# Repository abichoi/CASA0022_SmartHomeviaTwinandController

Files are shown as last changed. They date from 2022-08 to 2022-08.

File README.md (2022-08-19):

# Can the concept of a smart home be used in a small living space and linked to a physical model with two-way communication for real-time IoT data?
This repository is a part of a dissertation for UCL MSc Connected Environments.

## Hypothesis: Deploying a smart home system in a small living space via a physical twin and controller communication model.

## Aims
The aims of this dissertation is to investigate the possibility of deploying a smart home in a small living space and utilise the data collected by the smart home system through a physical ‘twin’ model. 

## Methodology 
A smart home based on Home Assistant is deployed in a student accomadation studio room with the following layout.

In addition, a physical twin and a controller are 3D printed and laser cut.

### Circuits  
#### Physical Twin  
  
  
#### Controller  
  

### Code
[Code Explanation](https://github.com/abichoi/CASA0022_SmartHomeviaTwinandController/blob/main/Physical_Devices_Code/Code_Explanation.md)

## Results
It is possible to deploy a smart home in a small living space and utilise the data collected by the smart home outside the system via a physical twin and controller. However, it is noted that the potential of the smart home is limited as it is easy for sensors' detection areas to overlay and it is difficult to differentiate different activitis in the same area.

## Demostration
A demonstration video of HASS Automations used in this dissertation on YouTube (https://youtu.be/vFsg55t07NU)

## Resulted Devices
### Physical Twin with 3D Printed Walls


### Physical Twin with Laser Cut Walls


### Controller with 3D Printed Cover


### Controller with Laser Cut Cover
  

### Self Built Air Monitor


## Used Softwares and Hardwares
### General
1. Modeling Software: Autodesk Fusion 360
2. 3D Printer: Original Prusa i3 MK3S+ 3D printer

### Physical Twin
1. Laser Cutter: Piranha Bodor laser cutter/ Trotec laser cutter
2. Laser Cutter Software: RD Works version 7/ Rhino
3. Servo Driver PCA9685
4. NodeMCU
5. Micro USB to USB-A or USB-C cable
6. Servo Motor x3
7.  2.9" E-Ink Display Module
8. LED
9. 220Ω Resistor
10. NeoPixel Stick
11. Power Bank: Anker PowerCore 20000 PD (Optional)
#### Files
Version 1: PhysicalTwin_3DPrintWall_Github v3.f3d  
Version 2: PhysicalTwin_LaserCutWall_Github v8.f3d, the PhysicalTwin_Walls folder in DXF folder

### Controller
1. Laser Cutter: Piranha Bodor laser cutter/ Trotec laser cutter
2. Laser Cutter Software: RD Works version 7/ Rhino
3. NodeMCU
4. Micro USB to USB-A or USB-C cable
5. Push Button x 5
6. 10kΩ Resistor x 5
7. 4.7k Resistor
8. Potentiometer x2
9. Diode x2
10. Phomemo M02 Pocket Printer (Optional)
#### File
Buttons_GIthub v11.f3d, Controller folder in DXF folder

### Self-Built Air Monitor
1. Modeling Software: Autodesk Fusion 360
2. 3D Printer: Original Prusa i3 MK3S+ 3D printer
3. Pimoroni Enviro for Raspberry Pi
4. PMS5003 Particulate Matter Sensor
5. SGP30
6. Raspberry Pi 4B
#### File
SelfBuiltAirMonitor_Case_Github v3.f3d

### Smart Home
1. Smart Home Platform: Home Assistant OS
2. Raspberry Pi 4B
3. SONOFF Zigbee 3.0 USB Dongle Plus
4. Aqara Motion Sensor x3
5. Aqara TVOC Air Quality Monitor
6. Aqara Door and Window Sensor
7. TP-LINK Kasa Smart Bulb LB110
8. TP-Link Kasa Smart Light Strip KL430
#### Intergrations
1. MQTT
2. OpenWeatherMap
3. TP-Link Kasa Smart
#### Add-ons
1. File editor
2. Terminal & SSH
3. Grafana
4. InfluxDB
5. Zigbee2MQTT

## How to recreate this project
### Physical Twin
1. Connect the components according to the circuit diagram above and run the [code](https://github.com/abichoi/CASA0022_SmartHomeviaTwinandController/tree/main/Physical_Devices_Code/MQTT_EInk_Driver_LED_PIXEL) on NodeMCU through ArduinoIDE
2. Print out the 3D model of different parts one by one and assemble them just like the 3D model file. The wall has to be glued.
**Please note:**  
The furnitures can be printed at 10% infill (except the desk, chair, toilet, sinks and stove), so that the top of the physical twin won't be too heavy.  
3. Laser cut the walls using the DXF files in the [PhysicalTwin_Walls folder](https://github.com/abichoi/CASA0022_SmartHomeviaTwinandController/tree/main/DXF/PhysicalTwin_Walls) if you would like to have a clear wall. Afterwards, glue the walls together

### Controller
1. Connect the components according to the circuit diagram above and run the [code](https://github.com/abichoi/CASA0022_SmartHomeviaTwinandController/tree/main/Physical_Devices_Code/buttons) on NodeMCU through ArduinoIDE
2. Print out the 3D model of the cover and base of the controller
3. Laser cut the cover using the DXF files in the [Controller folder](https://github.com/abichoi/CASA0022_SmartHomeviaTwinandController/tree/main/DXF/Controller)if you would like to see be able to see the circuit
4. Instruction on the controller is printed with Phomemo M02 Pocket Printer, this is optional

### Self Built Air Monitor
1. Connect the Enviro to Raspberry Pi and SGP30 and PMS5003 to Enviro according to the table below  

| Enviro  | Other Compoenents |
| --- | --- |
| 3V3  | SGP30 VIN  |
| GND  | SGP30 GND  |
| SCL  | SGP30 SCL  |
| SDA  | SGP30 SDA  |
| PM  | PMS5003  |

2. Create a .env file to store the MQTT credentials follwing this [tutorial](https://www.geeksforgeeks.org/how-to-hide-sensitive-credentials-using-python/) with the following format
```
MQTT_BROKER = "YOUR_MQTT_BROKER"
MQTT_BROKER_PORT = YOUR_PORT
MQTT_TOPIC = "YOUR_MQTT_TOPIC"
USERNAME = "YOUR_USER_NAME"
PASSWORD = "YOUR_PASSWORD"
```
4. Run the [code](https://github.com/abichoi/CASA0022_SmartHomeviaTwinandController/blob/main/Physical_Devices_Code/SelfBuiltAirMonitor.py) on Raspberry Pi

### Home Assistant
[Setps to recreate Home Assistant](https://github.com/abichoi/CASA0022_SmartHomeviaTwinandController/blob/main/Home_Assistant/RecreateHASS.md)

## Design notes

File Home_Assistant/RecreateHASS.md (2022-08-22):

# Steps to Recreate HASS in this dissertation
1. Pair your WiFi devices to your WiFi and connect Sonoff Zigbee Dongle
2. HASS installation: https://www.home-assistant.io/installation/raspberrypi
3. Follow the steps on the WebUI
4. HASS should automatically search for devices. If not, install the corresponding intergration manually.
5. Install the intergrations and add-on listed below:
    #### Intergrations
    1. MQTT
    2. OpenWeatherMap
    3. TP-Link Kasa Smart
    #### Add-ons
    1. File editor
    2. Terminal & SSH
    3. Grafana
    4. InfluxDB
    5. Zigbee2MQTT 
 
    [A Tutorial on how to install InfluxDB and Grafana](https://www.youtube.com/watch?v=rXF-LycbjoA) by [Smart Home Junkie on YouTube](https://www.youtube.com/c/SmartHomeJunkie)  
    **Please note:**  
    When pairing devices with Zigbee2MQTT (Z2M), it is possible that you would need to pair and disconnect them a few times to get all the entities.   
    For Aqara TVOC monitor, when pairing it with Z2M, press the button every second until it is paired to get all the entities (TVOC, Humidity, Temeperature), it is possible that you would need to repeat pairing it a lot of times until it works. 
   
7. To add the values of the device status to HASS, edit the configuration.yaml in your HASS with the File editor add-on. The [configuration.yaml](https://github.com/abichoi/CASA0022_SmartHomeviaTwinandController/blob/main/Home_Assistant/configuration.yaml) file used in this dissertation is provided in this Home_Assistant folder.  
   **Please note:**  
   Please make sure the name and unique_id are correct. If you change it afterwards, HASS will not store the previous data in the new name.
8. After ensuring all devices are connected to HASS, add automations by editing automations.yaml or through the "Automations & Scenes" tab in the Settings. The [automations.yaml file](https://github.com/abichoi/CASA0022_SmartHomeviaTwinandController/blob/main/Home_Assistant/automations.yaml) used in this dissertation is provided in this Home_Assistant folder and the explanation of automations is in [automation_explain.pdf](https://github.com/abichoi/CASA0022_SmartHomeviaTwinandController/blob/main/Home_Assistant/automation_explain.pdf).   
   **Please note:**  
   If the automations with time triggers/conditions are not working at that specific time, it is possible that you need to set up your time zone in Settings > System > General.

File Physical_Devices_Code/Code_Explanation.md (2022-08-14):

# Code Explanation
## MQTT_EInk_Driver_LED_PIXEL
### Device: Physical Twin
#### Detail explanation:
##### _setup()_
The NodeMCU would initialise the NeoPixel, servo motors and the e-ink display, connect to WiFi by running the startWiFi() function, connect to the MQTT and set callback() as the call back of the MQTT.
##### _startWifi()_
This function attempts to connect to the WiFi with the two WiFi credentials provided in _secret.h_, where all the WiFi and MQTT credentials and the topics are stored. It attempts to connect to the WiFi with the credentials named _SECRET_SSID1_ and _SECRET_PASS1_ in secret.h for 6 seconds. If it is not able to connect to the WiFi, then it would use the credentials named _SECRET_SSID2_ and _SECRET_PASS2_ for 10 seconds. The function will be looped until it is connected to WiFi. During the making of this project, the model was moved between the Lab and the studio room. To avoid having to change the WiFi credentials and upload the code every time the model is moved, two sets of credentials are stored in the secret.h and this function is changed so that it can connect to two different WiFi.
##### _pulseWidth()_
This function is used to convert the angle motor is turning to pulse width. 
##### _loop()_
At the beginning of the loop, if the LED and NeoPixel are on but not caused by the MQTT values, they will be turned off. This is written as they are always on when the physical twin is powered on. If the MQTT is disconnected, _reconnect()_ is called and this function connects back to the WiFi and MQTT. 
##### _callback()_
This function prints out the received message’s topic and its size. Then, it will read the message character by character and store it into a variable named combine. After that, the combine is terminated adding a NULL at the end of the variable. At last, the combine is stored in a variable according to the topic if the values are the humidity, temperature and TVOC of the room and the location of the user. For other values such as the status of the doors, window, light blub and light strip, the values are used to control the motors, LED, and NeoPixel after identifying the topic of the message. For example, if the value of the door contact sensor is true, the motor will close the door in the twin. If the value of the light strip colour is changed, then NeoPixel will change to that colour as well. 
##### _refreshdisplay()_
This function refreshes the e-ink display so that it shows the humidity, temperature, TVOC and the location of the user every time one of these values changes.

## buttons
### Device: Controller
#### Detail explanation:
##### _setup()_
The NodeMCU would connect to WiFi by running the startWiFi() function, which is identical to the one in MQTT_EInk_Driver_LED_PIXEL, and connect to the MQTT. 
##### _sendMQTT()_
This function is used to publish messages into MQTT.
##### _loop()_
First, reconnect(), the same as the one in MQTT_EInk_Driver_LED_PIXEL, is called to connect back to the WiFi or MQTT if MQTT is disconnected. Then, the status of the push buttons is read. If the desk lamp or the light strip buttons are pressed for more than 1 second, then it would be counted as long pressed, and it will read in the value of the corresponding potentiometer and send it to MQTT until the button is released. Otherwise, the corresponding light will be toggled through MQTT topics. If cold white, warm white or red buttons are pressed, then one of their MQTT topics will receive a 1 and the rest will receive a 0. The changes in the MQTT topics will trigger the automation mentioned in MQTT_EInk_Driver_LED_PIXEL.

## SelfBuiltAirMonitor.py
### Device: Self Built Air Monitor
This code is a combination of the following two python scripts in Pimoroni's Github repository:
1. https://github.com/pimoroni/enviroplus-python/blob/master/examples/mqtt-all.py
2. https://github.com/pimoroni/sgp30-python/blob/ef99b705293d5f92c2b6487d460ab42e4a728440/examples/test.py
#### Detail explanation:
It first get the MQTT credentials that are stored as environment variables and attemps to connect with the MQTT. Then it reads the values from BME280, PMS5003 and SGP30. After that, it publishes the values to the MQTT. At last, it displays the Raspberry Pi seial, WiFi status, connected MQTT name and the CPU temperature of the Raspberry Pi on the LCD display on the Enviro. 
#### Tutorial
A guide on how to store credetials as environment variables for python files: https://www.geeksforgeeks.org/how-to-hide-sensitive-credentials-using-python/

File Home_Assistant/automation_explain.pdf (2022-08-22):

Name | Action | Trigger | Condition | Active Time
SGP30 has error | Send notification to user’s smartphone with “SGP30 is malfunctioning! Go check it!” as the message | VOC value from Enviro+ is below 2 for 24 hours/ CO2 value from Enviro+ is below 405 for 24 hours/ | / | All the time
Sleep Time | After waiting for 3 minutes, check if the motion sensors in the kitchen and desk areas are not detecting motions. If yes, the lights will decrease their brightness by 10% every 1 minute | Bed area motion sensor detects motion | Light strip is on | 2100-0500
Twin Change Lamp Brightness | If the controller changes the light bulb brightness, the bulb will change according to that brightness | MQTT topic "student/CASA0022/ucfnsmc/twin/LampBrightness" is updated | / | All the time
Twin Change Light Strip Brightness | If the controller changes the light strip brightness, the light strip will change according to that brightness | MQTT topic "student/CASA0022/ucfnsmc/twin/StripBrightness" is updated | / | All the time
Twin change light strip to cold white | If the cold white button on the controller is pressed, turn on the light strip to maximum brightness with a mired of 260 | MQTT topic "student/CASA0022/ucfnsmc/twin/ColdLight" is updated | Payload of "student/CASA0022/ucfnsmc/twin/ColdLight" is 1 | All the time
Twin change light strip to red | If the red button on the controller is pressed, the light strip will flash in red 5 times at maximum brightness for 5 times and stay on after that | MQTT topic "student/CASA0022/ucfnsmc/twin/RedLight" is updated | Payload of "student/CASA0022/ucfnsmc/twin/RedLight" is 1 | All the time
Twin change light strip to warm white | If the warm white button on the controller is pressed, turn on the light strip to maximum brightness with a mired of 390 | MQTT topic "student/CASA0022/ucfnsmc/twin/WarmLight" is updated | Payload of "student/CASA0022/ucfnsmc/twin/WarmLight" is 1 | All the time
Twin toggle lamp | If the desk lamp on/off button on the controller is pressed, toggle the light bulb | MQTT topic "student/CASA0022/ucfnsmc/twin/LampButton" payload toggles between 0 and 1 | / | All the time
Twin toggle light strip | If the light strip on/off button on the controller is pressed, toggle the light strip | MQTT topic "student/CASA0022/ucfnsmc/twin/StripButton" payload toggles between 0 and 1 | / | All the time
Update Light Bulb Status | Send the status of the light bulb to MQTT topics: student/CASA0022/ucfnsmc/DeskLamp/OnorOff or student/CASA0022/ucfnsmc/DeskLamp/Brightness | Light bulb turned on or off/ Light bulb’s brightness changed | / | All the time
Update Light Strip Status | Send the status of the light strip to MQTT topics: “student/CASA0022/ucfnsmc/LightStrip/OnorOff” or “student/CASA0022/ucfnsmc/LightStrip/Brightness” or “student/CASA0022/ucfnsmc/LightStrip/rgb_color” or “student/CASA0022/ucfnsmc/LightStrip/Brightness255” | Light strip turned on or off/ Light strip’s brightness changed/ Light strip’s colour changed/ | / | All the time
Update Where The User Is | If a motion sensor is detecting motion, a message with the corresponding area will be sent to “student/CASA0022/ucfnsmc/Location”: Desk: Area 1 Bed: Area 2 Kitchen: Area 3 | One of the motion sensors’ statuses changed | / | All the time
VOC is high | Send notification to user’s smartphone with “VOC level is higher than normal Open the window!” as the message and light strip flash in blue for 2 times | Aqara air monitor’s TVOC level is changed or the window is opened then closed | TVOC level is higher than 100 and the window is closed | 0600-2200
When it is late and user is still at the desk | Change the light strip colour into a warm white with a mired of 390 and change the light bulb to 80% brightness | Desk motion sensor is detecting a motion | Light bulb and light strip are on | 2200-0600
When User Come Back | Turn on the light strip to maximum brightness with a mired of 343 | Main door or bathroom door is closed then opened and stayed open for 4 seconds | Light strip is off | All the time
When user is in bathroom | Turn off the lights and send “Area 4” to MQTT topic “student/CASA0022/ucfnsmc/Location” | Bathroom door opened and then closed and stayed closed for 10 minutes | None of the motion sensors is detecting motion and the light strip is on
When user is in desk area | Turn on the light bulb at maximum brightness and light strip at maximum brightness with a mired of 260 | Desk area motion sensor changed from not detecting motion to detecting | Light bulb is off | 0700-2200
When user is not in the desk area | Turn off the light bulb | Desk area motion sensor changed from detecting motion to not detecting | / | All the time
When User Left | Turn off both lights and send “Left” to MQTT topic “student/CASA0022/ucfnsmc/Location” | Main door is opened then closed and stayed closed for 3 minutes | All motion sensors cannot detect a motion and either the light bulb or light strip is on | All the time
When user wake up in the middle of the night | Turn on the light strip at 20% brightness with a mired of 390 | Bed area motion sensor changed from not detecting motion to detecting | All lights are off | 2200-0559
When user wake up in the morning | Turn on the light strip at 80% brightness with a mired of 390 | Bed area motion sensor changed from not detecting motion to detecting | Both lights are off | 0600-1100

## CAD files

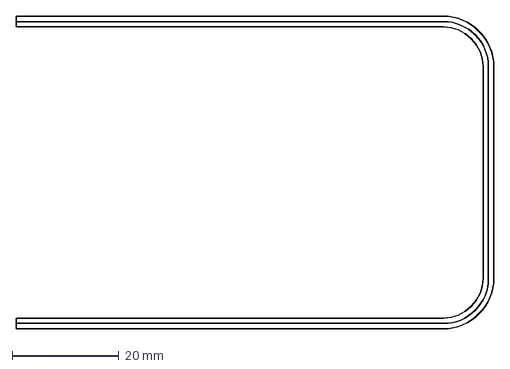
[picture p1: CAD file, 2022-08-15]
DXF/Controller/buttoncover_bottom.dxf
89.7 x 58.7 mm

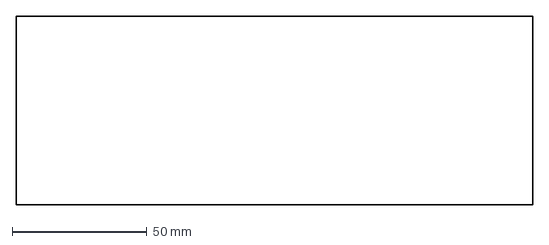
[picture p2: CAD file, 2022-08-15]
DXF/PhysicalTwin_Walls/B4.dxf
191.5 x 69.8 mm

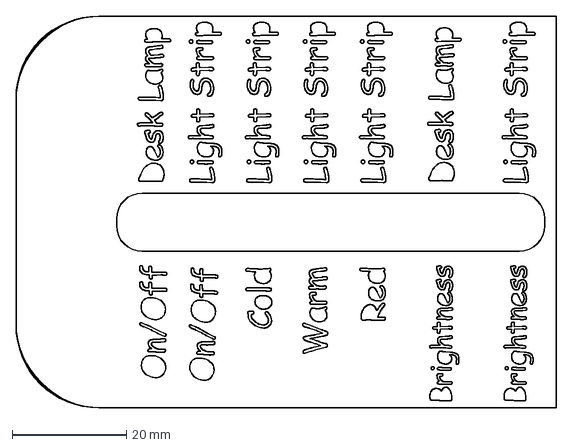
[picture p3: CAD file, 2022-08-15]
DXF/Controller/buttoncover_top.dxf
94.7 x 68.7 mm

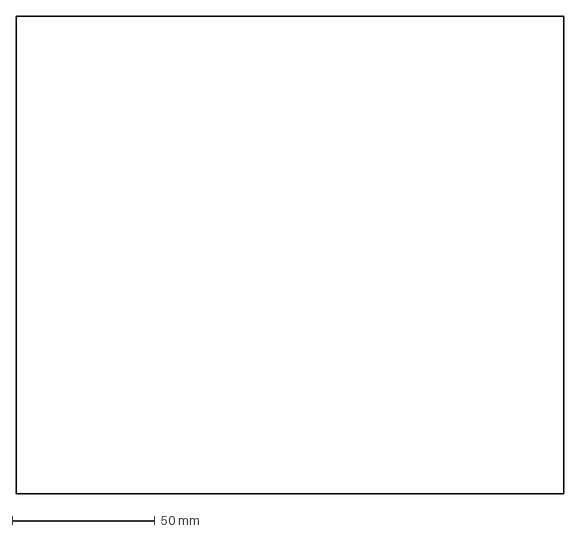
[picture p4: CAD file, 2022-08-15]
DXF/PhysicalTwin_Walls/B1.dxf
191.5 x 166.9 mm

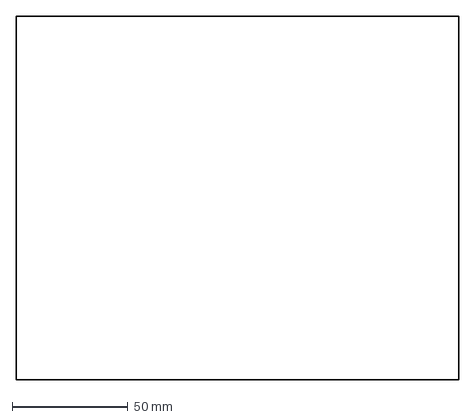
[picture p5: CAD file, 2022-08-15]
DXF/PhysicalTwin_Walls/B6.dxf
191.5 x 157.1 mm

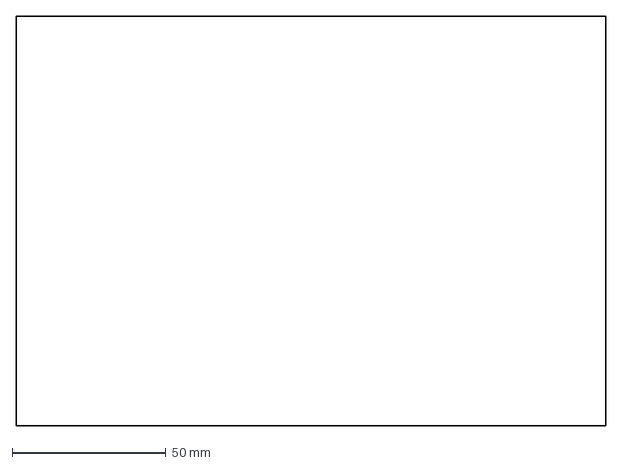
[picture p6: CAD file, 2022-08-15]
DXF/PhysicalTwin_Walls/1.dxf
191.5 x 132.9 mm

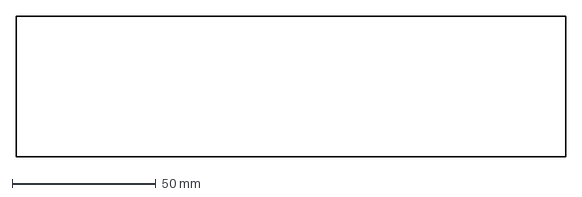
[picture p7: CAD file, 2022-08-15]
DXF/PhysicalTwin_Walls/5.dxf
191.5 x 49.0 mm

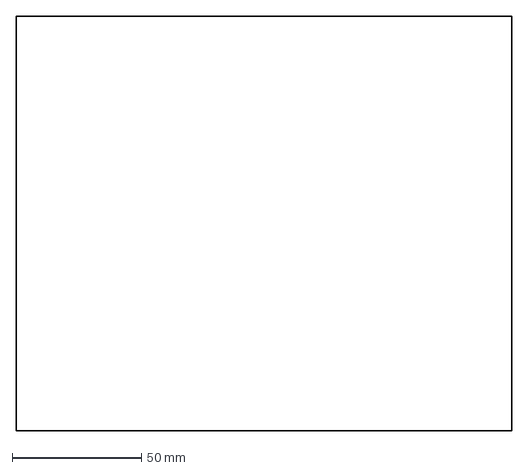
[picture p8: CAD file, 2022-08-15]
DXF/PhysicalTwin_Walls/2.dxf
191.5 x 160.1 mm

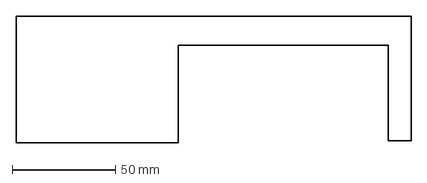
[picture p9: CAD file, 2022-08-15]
DXF/PhysicalTwin_Walls/B5.dxf
191.5 x 61.4 mm

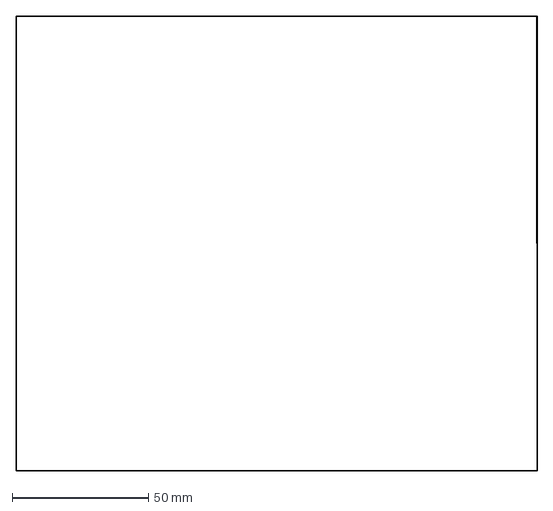
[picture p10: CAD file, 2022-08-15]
DXF/PhysicalTwin_Walls/4.dxf
191.5 x 166.9 mm

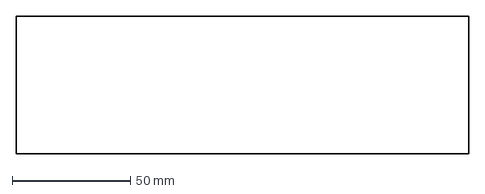
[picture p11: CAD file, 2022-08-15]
DXF/PhysicalTwin_Walls/B2.dxf
191.5 x 58.2 mm

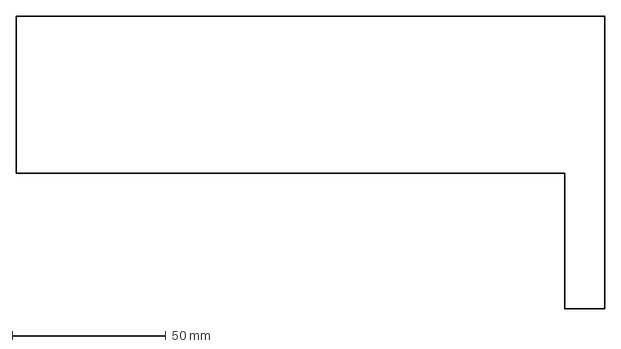
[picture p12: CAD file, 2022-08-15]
DXF/PhysicalTwin_Walls/B3.dxf
191.5 x 95.0 mm

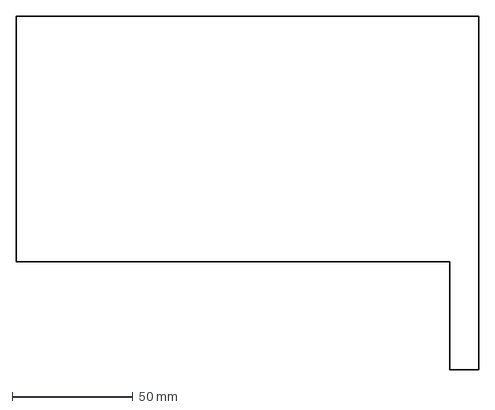
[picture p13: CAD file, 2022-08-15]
DXF/PhysicalTwin_Walls/3.dxf
191.5 x 146.4 mm

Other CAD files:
Fusion360/SelfBuiltAirMonitor_Case_Github v3.f3d

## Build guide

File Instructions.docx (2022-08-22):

Instructions:

1. Power the Physical Twin with the USB-A cable.
2. Wait until the LED on the NeoPixel Strip turns off.
3. Check if the values on the E-Ink display is updated within a minute.

If it did, the device is connected to WiFi.

Note:

1. Unless the motion/contact sensors’ state changes, the sensors will refresh the MQTT topics every 55 mins.
2. The E-ink display shows the TVOC, Humidity and Temperature detected by the Self-Built Air Monitor, which updates every minute. The location of the user will only update when motion sensors detect motion or the main door moves.

Instructions:

The Self-Built Air Monitor should be running the code already.

If not,

1. Connect the Raspberry Pi with a monitor and a mouse
2. Run the code file at /home/pi/Pimoroni/SelfBuiltAirMonitor.py

Instructions:

1. Power the Controller with the USB-A cable.
2. Wait 1-2 mins for the Controller to connect to the WiFi and MQTT

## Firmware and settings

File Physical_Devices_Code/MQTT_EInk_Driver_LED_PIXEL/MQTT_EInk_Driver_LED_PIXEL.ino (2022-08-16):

#include <ESP8266WiFi.h>
#include <ezTime.h>
#include <PubSubClient.h>
#include <ArduinoJson.h>

#include "secret.h"
const char* ssid1 = SECRET_SSID1;
const char* password1 = SECRET_PASS1;
const char* ssid2 = SECRET_SSID2;
const char* password2 = SECRET_PASS2;
const char* mqttserver = SECRET_MQTTURL;
const char* mqttuser = SECRET_MQTTUSER;
const char* mqttpass = SECRET_MQTTPASS;

const int mqttport = 1884;

char* air;
String received_test;
float humi= 0;
float temp = 0;
float voc = 0;
String location = "Waiting for update";
bool maindoor_contact = false;
bool bathdoor_contact = false;
bool window_contact = false;
bool strip_onoff = false;
String strip_rgb;
byte  strip_R = 0;
byte  strip_G = 0;
byte  strip_B = 0;
float strip_brightness;
bool lamp_onoff = false;
int lamp_brightness;

char * ptr;

Timezone GB;

WiFiClient espClient;
PubSubClient client(espClient);
long lastMsg = 0;
char msg[50];
int value = 0;

const char topic_test[] = TOPIC_TEST;
const char topic_air[] = TOPIC_AIR;
const char topic_air2[] = TOPIC_ENVIROPLUS;
const char topic_location[] = TOPIC_LOCATION;
const char topic_main_door[] = TOPIC_DOOR1;
const char topic_bath_door[] = TOPIC_DOOR2;
const char topic_window[] = TOPIC_DOOR3;
const char topic_strip_onoff[] = TOPIC_STRIP_ONOFF;
const char topic_strip_rgb[] = TOPIC_STRIP_RGB;
const char topic_strip_brightness[] = TOPIC_STRIP_BRIGHTNESS;
const char topic_lamp_onoff[] = TOPIC_LAMP_ONOFF;
const char topic_lamp_brightness[] = TOPIC_LAMP_BRIGHTNESS;


//GxEPD e-ink display
#include <GxEPD.h>
// display class
#include <GxGDEM029T94/GxGDEM029T94.h>      // 2.9" b/w
// FreeFonts from Adafruit_GFX
#include <Fonts/FreeMonoBold9pt7b.h>
#include <Fonts/FreeMonoBold12pt7b.h>
#include <Fonts/FreeMonoBold18pt7b.h>
#include <Fonts/FreeMonoBold24pt7b.h>

#include <GxIO/GxIO_SPI/GxIO_SPI.h>
#include <GxIO/GxIO.h>

GxIO_Class io(SPI, /*CS=D8*/ SS, /*DC=D3*/ 0, /*RST=D0*/ 16); // original does not work;
GxEPD_Class display(io, /*RST=D0*/ 16, /*BUSY=D6*/ 12); // adapted from http://psychomechanics.de/?p=738&page=2

//driver
#include "Wire.h"
#include "Adafruit_PWMServoDriver.h"
Adafruit_PWMServoDriver pwm = Adafruit_PWMServoDriver(0x40);

#define MIN_PULSE_WIDTH 600
#define MAX_PULSE_WIDTH 2600
#define FREQUENCY 50

//PIXEL
#include <Adafruit_NeoPixel.h>
#define DIN D4
#define NUMPIXELS 8
Adafruit_NeoPixel pixels(NUMPIXELS,DIN, NEO_GRB + NEO_KHZ800);

//LED
#define LED D9

void setup() {
  // open serial connection
  Serial.begin(115200);

  //set up NeoPixel
  pixels.begin();
  pixels.clear();
  for (int i=0; i<NUMPIXELS; i++){
    pixels.setPixelColor(i,pixels.Color(0, 0, 0));
  }
  pixels.show();

  //set up servo motor
  Serial.println("setup servo motor");
  pwm.begin();
  pwm.setPWMFreq(FREQUENCY);
  pwm.setPWM(0, 0, pulseWidth(90)); //main door
  pwm.setPWM(1, 0, pulseWidth(90)); //bathroom door
  pwm.setPWM(2, 0, pulseWidth(90)); //window
  Serial.println("setup servo motor DONE");
  
  
  delay(100);

  startWifi();

  // get real date and time
  waitForSync();
  Serial.println("UTC: " + UTC.dateTime()); 
  GB.setLocation("Europe/London");
  Serial.println("London time: " + GB.dateTime());  

  //set up MQTT
  client.setServer(mqttserver, mqttport);
  client.setCallback(callback);

  //set up e ink display
  Serial.println("setup e-ink");
  display.init(115200);
  Serial.println("setup e-ink DONE");
  display.eraseDisplay();
  display.print("Getting Data");
  display.drawPaged(refreshdisplay);
  
}

int pulseWidth(int angle) {
  int pulse_wide, analog_value;
  pulse_wide = map(angle, 0, 180, MIN_PULSE_WIDTH, MAX_PULSE_WIDTH);
  analog_value = int(float(pulse_wide) / 1000000 * FREQUENCY * 4096);
  return analog_value;
}

void loop() {
  if(strip_onoff == false){
    pixels.clear();
    for (int i=0; i<NUMPIXELS; i++){
      pixels.setPixelColor(i,pixels.Color(0, 0, 0));
    }
    pixels.show();
  }
  if(lamp_onoff == false){
    analogWrite(LED, 0);
  }
  if (!client.connected()) {
    reconnect();
  }
  client.loop();
}

//set up wifi
void startWifi(){
  // We start by connecting to a WiFi network
  Serial.println();
  Serial.print("Connecting to ");
  Serial.println(ssid1);
  WiFi.begin(ssid1, password1);
  int currentwifi = 1;
  unsigned long previousMillis = millis();
  // check to see if connected and wait until you are
  while (WiFi.status() != WL_CONNECTED) {
    delay(500);
    Serial.print(".");
    unsigned long currentMillis = millis();
     if (currentMillis - previousMillis >= 6000) {
      previousMillis = currentMillis;
      if (currentwifi == 1){
        Serial.print("Connecting to ");
        Serial.println(ssid2);
        WiFi.begin(ssid2, password2);
        currentwifi = 2;
      } else if (currentwifi == 2){
        Serial.print("Connecting to ");
        Serial.println(ssid1);
        WiFi.begin(ssid1, password1);
        currentwifi = 1;
      }
    }
    
  }
  Serial.println("");
  Serial.println("WiFi connected");  
  Serial.print("IP address: ");
  Serial.println(WiFi.localIP());
}

void callback(String topic, byte* payload, unsigned int length) {
  Serial.print("Message arrived [");
  Serial.print(topic);
  Serial.println("] ");
  char combine[length+1];
  for (int i = 0; i < length; i++) {
    combine[i]= (char)payload[i];
    Serial.print((char)payload[i]);
  }
  Serial.println();
  //terminate the message variable
  combine[length] = NULL;
  Serial.print(" bytes:");
  Serial.println(length);
  Serial.println(combine);
  Serial.println(topic);

  if (topic == topic_test){
    received_test = String(combine);
    Serial.print("received_test:");
    Serial.println(received_test);
  } else if (topic == topic_air2){
    Serial.print("air monitor update");
    StaticJsonDocument <256> doc;
    deserializeJson(doc,payload);
    humi  = doc["humidity"];
    temp = doc["temperature"];
    voc = doc["VOC"];
    Serial.print("humidity:");
    Serial.println(humi);    
    Serial.print("temperature:");
    Serial.println(temp);
    Serial.print("voc:");
    Serial.println(voc);
    display.drawPaged(refreshdisplay);
  }else if (topic == topic_location){
    location = String(combine);
    Serial.print("Location:");
    Serial.println(location);
    display.drawPaged(refreshdisplay);
  }else if (topic == topic_main_door){
    StaticJsonDocument <256> doc;
    deserializeJson(doc,payload);
    if (String(doc["contact"]) == "true"){
      maindoor_contact = true; //door closed
      pwm.setPWM(0, 0, pulseWidth(90)); //main door close
    } else{
      maindoor_contact = false; //door opened
      pwm.setPWM(0, 0, pulseWidth(0)); //main door open
      }
    Serial.print("maindoor_contact:");
    Serial.println(maindoor_contact);
  }else if (topic == topic_bath_door){
    StaticJsonDocument <256> doc;
    deserializeJson(doc,payload);
    if (String(doc["contact"]) == "true"){
      bathdoor_contact = true; //door closed
      pwm.setPWM(1, 0, pulseWidth(90)); //bathroom door close
    } else{
      bathdoor_contact = false; //door opened
      pwm.setPWM(1, 0, pulseWidth(0)); //bathroom door open
    }
    Serial.print("bathdoor_contact:");
    Serial.println(bathdoor_contact);
  }else if (topic == topic_window){
    StaticJsonDocument <256> doc;
    deserializeJson(doc,payload);
    if (String(doc["contact"]) == "true"){
      window_contact = true; //window closed
      pwm.setPWM(2, 0, pulseWidth(90)); //window door close
    } else{
      window_contact = false; //window opened
      pwm.setPWM(2, 0, pulseWidth(20 )); //window door open
     
    }
    Serial.print("window_contact:");
    Serial.println(window_contact);
  }else if (topic == topic_strip_onoff){
    if (strcmp(combine,"on")==0){
      strip_onoff = true;
    } else{
      strip_onoff = false;
     }
     Serial.print("strip_onoff:");
    Serial.println(strip_onoff);
  }else if (topic == topic_strip_rgb){
    strip_rgb = String(combine);
    int posred = strip_rgb.indexOf('(');
    String red = strip_rgb.substring(posred +1, posred +4);
    int posgrn = strip_rgb.indexOf(','); 
    String green = strip_rgb.substring(posgrn +1, posgrn +5);
    int posblu = strip_rgb.indexOf(')');
    String blue = strip_rgb.substring(posblu -3, posblu);
    strip_R = red.toInt(); 
    strip_G = green.toInt();
    strip_B = blue.toInt();
    Serial.print("strip_R:");
    Serial.println(strip_R);
    Serial.print("strip_G:");
    Serial.println(strip_G);
    Serial.print("strip_B:");
    Serial.println(strip_B);
    
    if (strip_onoff == true){
      for (int i=0; i<NUMPIXELS; i++){
      pixels.setPixelColor(i,pixels.Color(strip_R*strip_brightness, strip_G*strip_brightness, strip_B*strip_brightness));
      }
      pixels.show();
     } else{
      strip_onoff = false;
      strip_brightness = 0;
      strip_R = 0;
      strip_G = 0;
      strip_B = 0;
      pixels.clear();
      for (int i=0; i<NUMPIXELS; i++){
        pixels.setPixelColor(i,pixels.Color(0, 0, 0));
      }
      pixels.show();
     }
  }else if (topic == topic_strip_brightness){
    strip_brightness = atoi(combine);
    strip_brightness = strip_brightness/100;
    Serial.print("strip_brightness:");
    Serial.println(strip_brightness);
  }else if (topic == topic_lamp_onoff){
    if (strcmp(combine,"on")==0){
      lamp_onoff = true; //lamp is on
      analogWrite(LED, lamp_brightness);
    } else{
      lamp_onoff = false; //lamp is off
      analogWrite(LED, 0);
    }
    Serial.print("lamp_onoff:");
    Serial.println(lamp_onoff);
  }else if (topic == topic_lamp_brightness){
    lamp_brightness = atoi(combine);
    analogWrite(LED, lamp_brightness);
    Serial.print("lamp_brightness:");
    Serial.println(lamp_brightness);
  }
  Serial.print("humidity:");
    Serial.println(humi);    
    Serial.print("temperature:");
    Serial.println(temp);
    Serial.print("voc:");
    Serial.println(voc);
    Serial.print("Location:");
    Serial.println(location);
    Serial.print("maindoor_contact:");
    Serial.println(maindoor_contact);
    Serial.print("bathdoor_contact:");
    Serial.println(bathdoor_contact);
    Serial.print("window_contact:");
    Serial.println(window_contact);
    Serial.print("strip_onoff:");
    Serial.println(strip_onoff);
    Serial.print("strip_R:");
    Serial.println(strip_R);
    Serial.print("strip_G:");
    Serial.println(strip_G);
    Serial.print("strip_B:");
    Serial.println(strip_B);
    Serial.print("strip_brightness:");
    Serial.println(strip_brightness);
    Serial.print("lamp_onoff:");
    Serial.println(lamp_onoff);
    Serial.print("lamp_brightness:");
    Serial.println(lamp_brightness);

}

void reconnect() {
  startWifi();
  // Loop until we're reconnected
  while (!client.connected()) {
    Serial.print("Attempting MQTT connection...");
    // Create a random client ID
    String clientId = "ESP8266Client-";
    clientId += String(random(0xffff), HEX);
    // Attempt to connect
    if (client.connect(clientId.c_str(), mqttuser, mqttpass)) {
      Serial.println("connected");
      client.subscribe(topic_test);
      client.subscribe(topic_air);
      client.subscribe(topic_air2);
      client.subscribe(topic_location);
      client.subscribe(topic_main_door);
      client.subscribe(topic_bath_door);
      client.subscribe(topic_window);
      client.subscribe(topic_strip_onoff);
      client.subscribe(topic_strip_rgb);
      client.subscribe(topic_strip_brightness);
      client.subscribe(topic_lamp_onoff);
      client.subscribe(topic_lamp_brightness);
    } else {
      Serial.print("failed, rc=");
      Serial.print(client.state());
      Serial.println(" try again in 5 seconds");
      // Wait 5 seconds before retrying
      delay(500);
    }
  }
}

void refreshdisplay(){
  display.setTextColor(GxEPD_BLACK);
  display.setFont(&FreeMonoBold12pt7b);
  display.setTextSize(1);
  display.setRotation(1);
  display.setCursor(0, 0);
  display.println();
  display.print("Temperature:");
  display.print(temp);
  display.println("C");
  display.print("Humidity:");
  display.print(humi);
  display.println("%");
  display.print("TVOC:");
  display.print(voc);
  display.println("ppb");
  display.print("Location:");
  display.print(location);
  display.update();
}

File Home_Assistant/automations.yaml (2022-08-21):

- id: '1653675952507'
  alias: Update Light Bulb Status
  description: 'Publish Lamp Status to MQTT

    Whether it is on and the current brightness '
  trigger:
  - platform: state
    entity_id:
    - light.desklamp
    attribute: brightness
    for:
      hours: 0
      minutes: 0
      seconds: 0
  - platform: device
    type: changed_states
    device_id: 18fdd4c2e60f26092616d65ebb41bc43
    entity_id: light.desklamp
    domain: light
  condition: []
  action:
  - service: mqtt.publish
    data:
      topic: student/CASA0022/ucfnsmc/DeskLamp/OnorOff
      qos: '2'
      payload_template: '{{ states(''light.desklamp'') }}'
  - service: mqtt.publish
    data:
      topic: student/CASA0022/ucfnsmc/DeskLamp/Brightness
      qos: '2'
      payload_template: '{{ (states.light.desklamp.attributes.brightness) }}'
  mode: single
- id: '1653682244517'
  alias: Update Light Strip Status
  description: ''
  trigger:
  - platform: state
    entity_id:
    - light.lightstrip
    attribute: brightness
  - platform: state
    entity_id:
    - light.lightstrip
    attribute: rgb_color
  - platform: device
    type: changed_states
    device_id: ab20328f975dbb2cda819b0154accefa
    entity_id: light.lightstrip
    domain: light
  condition: []
  action:
  - service: mqtt.publish
    data:
      topic: student/CASA0022/ucfnsmc/LightStrip/OnorOff
      qos: '2'
      payload_template: '{{ states(''light.lightstrip'') }}'
  - service: mqtt.publish
    data:
      topic: student/CASA0022/ucfnsmc/LightStrip/Brightness
      qos: '2'
      payload_template: '{{ (states.light.lightstrip.attributes.brightness)/255*100
        }}'
  - service: mqtt.publish
    data:
      topic: student/CASA0022/ucfnsmc/LightStrip/rgb_color
      qos: '2'
      payload_template: '{{ (states.light.lightstrip.attributes.rgb_color)}}'
  - service: mqtt.publish
    data:
      topic: student/CASA0022/ucfnsmc/LightStrip/Brightness255
      qos: '2'
      payload_template: '{{ (states.light.lightstrip.attributes.brightness) }}'
  mode: single
- id: '1653683990822'
  alias: When User Left
  description: ''
  trigger:
  - platform: state
    entity_id:
    - binary_sensor.door1_contact
    for:
      hours: 0
      minutes: 3
      seconds: 0
    enabled: true
    from: 'off'
    to: 'on'
  condition:
  - condition: state
    entity_id: binary_sensor.motion1_occupancy
    state: 'off'
  - condition: state
    entity_id: binary_sensor.motion2_occupancy
    state: 'off'
  - condition: state
    state: 'off'
    entity_id: binary_sensor.motion3_occupancy
  - condition: or
    conditions:
    - condition: state
      entity_id: light.desklamp
      state: 'on'
    - condition: state
      entity_id: light.lightstrip
      state: 'on'
    enabled: true
  action:
  - type: turn_off
    device_id: 18fdd4c2e60f26092616d65ebb41bc43
    entity_id: light.desklamp
    domain: light
  - type: turn_off
    device_id: ab20328f975dbb2cda819b0154accefa
    entity_id: light.lightstrip
    domain: light
  - service: mqtt.publish
    data:
      topic: student/CASA0022/ucfnsmc/Location
      payload: Left
      qos: '2'
  mode: single
- id: '1653687235096'
  alias: When User Come Back
  description: ''
  trigger:
  - platform: state
    entity_id:
    - binary_sensor.door1_contact
    from: 'on'
    for:
      hours: 0
      minutes: 0
      seconds: 4
    to: 'off'
  - platform: state
    entity_id:
    - binary_sensor.door2_contact
    from: 'on'
    to: 'off'
    for:
      hours: 0
      minutes: 0
      seconds: 4
  condition:
  - condition: state
    entity_id: light.lightstrip
    state: 'off'
  action:
  - service: light.turn_on
    data:
      color_temp: 343
      brightness: 255
    target:
      device_id: ab20328f975dbb2cda819b0154accefa
  mode: single
- id: '1653687808023'
  alias: Sleep Time
  description: 'When Bed Motion Sensor is detected, a 2 min timer is set to countdown

    Desk motion sensor and Kitchen motion sensor''s occupancy will be off if the user
    is on the bed

    If user is on bed => decrease the brightness of both lights slowly (should take
    about 18 min) until they turn off
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

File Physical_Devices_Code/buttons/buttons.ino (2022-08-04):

#include <ESP8266WiFi.h>
#include <PubSubClient.h>
#include <ezTime.h>
#include "Wire.h"
#include "secret.h"
const char* ssid1 = SECRET_SSID1;
const char* password1 = SECRET_PASS1;
const char* ssid2 = SECRET_SSID2;
const char* password2 = SECRET_PASS2;
const char* mqttserver = SECRET_MQTTURL;
const char* mqttuser = SECRET_MQTTUSER;
const char* mqttpass = SECRET_MQTTPASS;
int mqttport = 1884;

Timezone GB;


const char topic_lampbutton[] = TOPIC_LAMPBUTTON;
const char topic_stripbutton[] = TOPIC_STRIPBUTTON;
const char topic_lampbrightness[] = TOPIC_LAMPBRIGHTNESS;
const char topic_stripbrightness[] = TOPIC_STRIPBRIGHTNESS;
const char topic_cold[] = TOPIC_COLD;
const char topic_warm[] = TOPIC_WARM;
const char topic_red[] = TOPIC_RED;


float readlamp_brightness;
float readstrip_brightness;
const int lamp_brightness = 5; //D1
const int strip_brightness = 4; //D2
const int lamp_button = 15; //D8
const int strip_button = 2; //D4
const int strip_cold = 14; //D5
const int strip_warm = 12; //D6
const int strip_red = 13; //D7
int short_press_time = 500;
int long_press_time  = 1000;

bool lamp_button_toogle = false;
bool strip_button_toogle = false;

int lastState_lamp_button = LOW;
int lastState_strip_button = LOW;
int lastState_strip_cold = LOW;
int lastState_strip_warm = LOW;
int lastState_strip_red = LOW;


bool isPressing_lamp_button = false;
unsigned long pressedTime_lamp_button = 0;
bool isLongDetected_lamp_button = false;

bool isPressing_strip_button = false;
unsigned long pressedTime_strip_button = 0;
bool isLongDetected_strip_button = false;

WiFiClient espClient;
PubSubClient client(espClient);
long lastMsg = 0;
char msg[50];
int value = 0;
 
void setup() {
  Serial.begin(115200);
  startWifi();
  
  // get real date and time
  waitForSync();

  Serial.println("UTC: " + UTC.dateTime()); 
  GB.setLocation("Europe/London");
  Serial.println("London time: " + GB.dateTime());  
  //set up MQTT
  client.setServer(mqttserver, mqttport);  

  pinMode(lamp_brightness, OUTPUT);
  pinMode(strip_brightness, OUTPUT);
}

//set up wifi
void startWifi(){
  // We start by connecting to a WiFi network
  Serial.println();
  Serial.print("Connecting to ");
  Serial.println(ssid1);
  WiFi.begin(ssid1, password1);
  int currentwifi = 1;
  unsigned long previousMillis = millis();
  // check to see if connected and wait until you are
  while (WiFi.status() != WL_CONNECTED) {
    delay(500);
    Serial.print(".");
    unsigned long currentMillis = millis();
     if (currentMillis - previousMillis >= 6000) {
      previousMillis = currentMillis;
      if (currentwifi == 1){
        Serial.print("Connecting to ");
        Serial.println(ssid2);
        WiFi.begin(ssid2, password2);
        currentwifi = 2;
      } else if (currentwifi == 2){
        Serial.print("Connecting to ");
        Serial.println(ssid1);
        WiFi.begin(ssid1, password1);
        currentwifi = 1;
      }
    }
    
  }
  Serial.println("");
  Serial.println("WiFi connected");  
  Serial.print("IP address: ");
  Serial.println(WiFi.localIP());
}

void sendMQTT(const char* topic, uint8_t msg) {
  Serial.print("message: ");
  Serial.println(msg);
  char payload[16];
  snprintf(payload, sizeof(payload), "%u", msg);
  client.publish(topic, payload);
}

void reconnect() {
  startWifi();
  // Loop until we're reconnected
  while (!client.connected()) {
    Serial.print("Attempting MQTT connection...");
    // Create a random client ID
    String clientId = "ESP8266Client-";
    clientId += String(random(0xffff), HEX);
    // Attempt to connect
    if (client.connect(clientId.c_str(), mqttuser, mqttpass)) {
      Serial.println("connected");
    } else {
      Serial.print("failed, rc=");
      Serial.print(client.state());
      Serial.println(" try again in 5 seconds");
      // Wait 5 seconds before retrying
      delay(500);
    }
  }
}
 
void loop() {
  if (!client.connected()) {
    reconnect();
    }
  client.loop();
  int currentState_strip_cold = digitalRead(strip_cold);
  int currentState_strip_warm = digitalRead(strip_warm);
  int currentState_strip_red = digitalRead(strip_red);
  int currentState_lamp_button = digitalRead(lamp_button);
  int currentState_strip_button = digitalRead(strip_button);
  
  if(lastState_lamp_button == LOW && currentState_lamp_button == HIGH) {        // button is pressed
    pressedTime_lamp_button = millis();
    isPressing_lamp_button = true;
    isLongDetected_lamp_button = false;
  } else if(lastState_lamp_button == HIGH && currentState_lamp_button == LOW) { // button is released
    if (isLongDetected_lamp_button){
    sendMQTT(topic_lampbrightness, readlamp_brightness);
    }
    else {
      if (lamp_button_toogle){
        lamp_button_toogle = false;
      } else {
        lamp_button_toogle = true;
        }
      sendMQTT(topic_lampbutton, lamp_button_toogle);
    }
    isLongDetected_lamp_button = false;
    isPressing_lamp_button = false;
  }

  if(isPressing_lamp_button == true) {
    long pressDuration_lamp_button = millis() - pressedTime_lamp_button;
    if( pressDuration_lamp_button > long_press_time ) {
      Serial.println("A long press is detected");
      isLongDetected_lamp_button = true;
      digitalWrite(lamp_brightness, HIGH); //  Turn D1 On
      digitalWrite(strip_brightness, LOW); // Turn D2 Off
      readlamp_brightness = analogRead(0);
      readlamp_brightness = round(readlamp_brightness/890 * 255);
      if (readlamp_brightness > 255){
        readlamp_brightness = 255;
        }
      Serial.println("readlamp_brightness:");
      Serial.println(readlamp_brightness);
    }
  }
  
  lastState_lamp_button = currentState_lamp_button;

  if(lastState_strip_button == LOW && currentState_strip_button == HIGH) {        // button is pressed
    pressedTime_strip_button = millis();
    isPressing_strip_button = true;
    isLongDetected_strip_button = false;
  } else if(lastState_strip_button == HIGH && currentState_strip_button == LOW) { // button is released
    if (isLongDetected_strip_button){
    sendMQTT(topic_stripbrightness, readstrip_brightness);
    }
    else {
      if (strip_button_toogle){
        strip_button_toogle = false;
      } else {
        strip_button_toogle = true;
        }
      sendMQTT(topic_stripbutton, strip_button_toogle);
    }
    isLongDetected_strip_button = false;
    isPressing_strip_button = false;
  }
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
